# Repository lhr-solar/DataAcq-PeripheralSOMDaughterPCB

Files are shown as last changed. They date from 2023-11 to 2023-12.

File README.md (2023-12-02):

# Telemetry Peripheral SOM Daughterboard IMU
Author: Frank Li and Jim Fang

This board takes inputs from an IMU, airflow sensor, and three temp sensors and interfaces with the BPS Leader SOM.



## BOM

[**Mouser Cart**](https://www.mouser.com/ProjectManager/ProjectDetail.aspx?AccessID=6005ad65a9)

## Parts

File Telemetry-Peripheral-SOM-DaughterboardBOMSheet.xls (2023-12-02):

Mouser # | Mfr. # | Manufacturer | Description | Order Qty. | Price (USD) | Ext.: (USD)
 |  |  | 3.3V TestPoint (3.3V_TP1) | 1
 |  |  | 0.1u Capacitors (C1-C5, C8, C10, C12) | 8
 |  |  | 1u Capacitor (C6) | 1
 |  |  | 10n Capacitor (C7, C9, C11) | 3
875-HZ0805B222R-10 | HZ0805B222R-10 | Laird Performance Materials | 2.2K Ferrite Beads (FB1-FB3) | 3 | $0.15 | $0.45
 |  |  | GND TestPoint (GND_TP1) | 1
972-FS3000-1015 | FS3000-1015 | Renesas Electronics | Airflow Sensor (IC1) | 1 | $19.80 | $19.80
538-53307-2071 | 53307-2071 | Molex | Leader SOM Connector | 1 | $2.48 | $2.48
538-43650-0315 | 43650-0315 | Molex | Temperature Sensor Connectors (J2-J4) | 3 | $1.21 | $3.63
 |  |  | Mounting Holes (MH1, MH2) | 2
71-CRCW0805-50 | CRCW080550R0FKTA | Vishay | 50 Resistor (R1) | 1 | $0.25 | $0.25
755-SDR10EZPJ302 | SDR10EZPJ302 | ROHM Semiconductor | 3K Resistor (R2-R4) | 3 | $0.20 | $0.60
 |  |  | TestPoints for certain parts (TP1-TP5) | 5
511-LSM6DSVTR | LSM6DSVTR | STMicroelectronics | Inertial Motion Unit (U1) | 1 | $7.33 | $7.33

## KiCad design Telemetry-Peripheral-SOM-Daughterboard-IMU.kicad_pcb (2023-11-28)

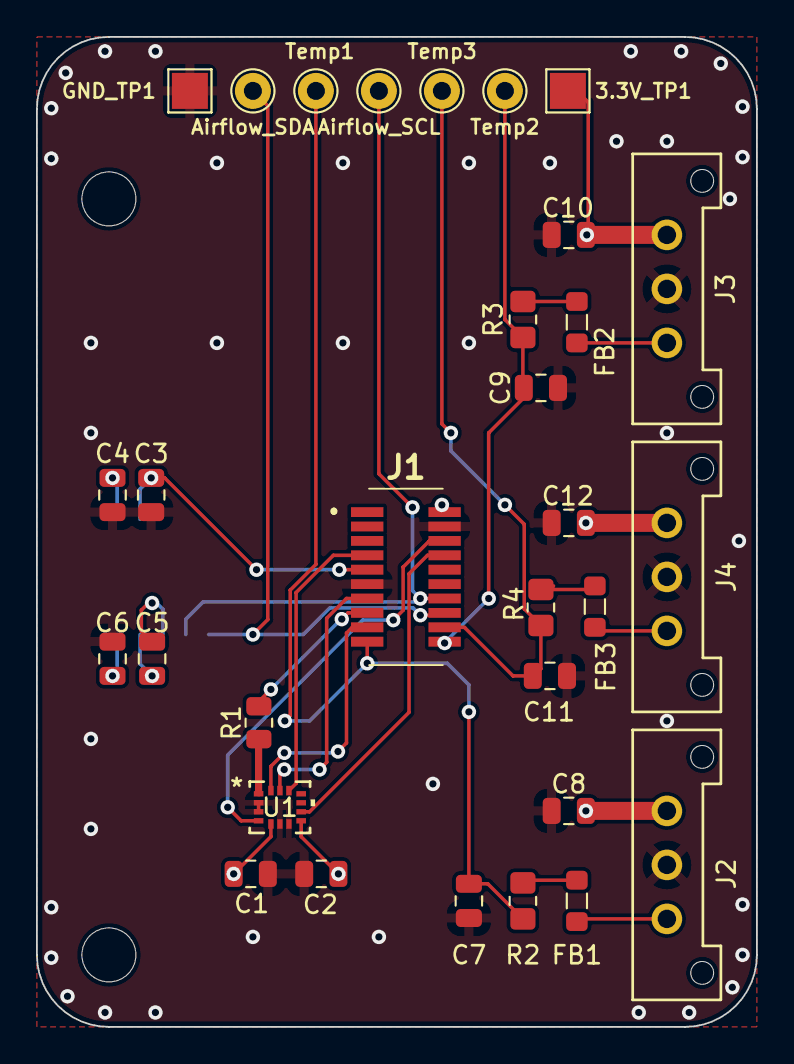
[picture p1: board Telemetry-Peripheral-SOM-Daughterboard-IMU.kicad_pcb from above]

Board: 2 copper layers, 40.0 x 55.0 mm, 34 parts (1 on the bottom side), 24 nets.

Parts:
3.3V_TP1: TestPoint; TestPoint_Pad_2.0x2.0mm
Airflow_SCL: TestPoint; TestPoint_THTPad_D2.0mm_Drill1.0mm
Airflow_SDA: TestPoint; TestPoint_THTPad_D2.0mm_Drill1.0mm
C1, C2, C3, C4, C5, C8, C10, C12: 0.1u; C_0805_2012Metric
C6: 1u; C_0805_2012Metric
C7, C9, C11: 10n; C_0805_2012Metric
FB1, FB2, FB3: 2.2k; L_0805_2012Metric_Pad1.05x1.20mm_HandSolder
GND_TP1: TestPoint; TestPoint_Pad_2.0x2.0mm
IC1: FS3000-1015; FS30001015
J1: Conn_02x10_Odd_Even; Molex_53307-2071
J2, J3, J4: Conn_01x03_Pin; Molex_MicroFit3.0_1x3xP3.00mm_PolarizingPeg_Vertical
MH1, MH2: M.3; MountingHole_3mm
R1: 50; R_0805_2012Metric
R2, R3, R4: 3k; R_0805_2012Metric_Pad1.20x1.40mm_HandSolder
Temp1, Temp2, Temp3: TestPoint; TestPoint_THTPad_D2.0mm_Drill1.0mm
U1: LSM6DSV; LGA14-L_2P59X3P1X0P5_STM

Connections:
+3.3V: 3.3V_TP1.1, C1.1, C2.1, C3.1, C8.1, C10.1, C12.1, IC1.2 (VIN), J1.2, J1.9, J2.1, J3.1, J4.1, U1.5 (VDD_IO), U1.8 (VDD)
/I2C1_SCL: Airflow_SCL.1, IC1.7 (SCL), J1.14
/I2C1_SDA: Airflow_SDA.1, IC1.6 (SDA), J1.16
/I2C2_SCL: J1.8, U1.9 (INT2)
/I2C2_SDA: J1.6, U1.4 (INT1)
/PA1: C9.1, J1.20, R3.1, Temp2.1
/PA2: C11.1, J1.18, R4.1, Temp3.1
/SPI1_MISO: J1.15, R1.1
/SPI1_MOSI: J1.17, U1.14 (SDA)
/SPI1_NSS: C7.1, J1.19, R2.1, Temp1.1
/SPI1_SCK: J1.13, U1.13 (SCL)
/SPI2_NSS: J1.7, U1.12 (CS)
GND: C1.2, C2.2, C3.2, C4.2, C6.2, C7.2, C8.2, C9.2, C10.2, C11.2, C12.2, GND_TP1.1, IC1.3 (GND), J1.4, J1.11, J2.2, J3.2, J4.2, U1.2 (SDX), U1.3 (SCX), U1.6 (GND), U1.7 (GND)
unnamed: FB1.1, R2.2
unnamed: FB2.1, R3.2
unnamed: FB3.1, R4.2
unnamed: C5.1, IC1.8 (TP1)
unnamed: C5.2, IC1.9 (TP2)
unnamed: C6.1, IC1.10 (VCM)
unnamed: C4.1, IC1.1 (VREG)
unnamed: FB1.2, J2.3
unnamed: FB2.2, J3.3
unnamed: FB3.2, J4.3
unnamed: R1.2, U1.1 (SDO/SA0)

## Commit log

2023-08-28 very basic daughterboard
    [Peripheral-SOM-Daughterboard.kicad_pcb, Telemetry-Peripheral-SOM-Daughterboard-IMU.kicad_pcb, Telemetry-Peripheral-SOM-Daughterboard-IMU.kicad_sch]
2023-09-29 created file for airflow sensor
    [Telemetry-Peripheral-SOM-Daughterboard-IMU.kicad_sch, airflowSensor.kicad_sch]
2023-09-29 created temperature sensor symbol and schematic
    [Telemetry-Peripheral-SOM-Daughterboard-IMU.kicad_sch, temperatureSensor.kicad_sch]
2023-09-30 Changes to airflow sch
    [airflowSensor.kicad_sch]
2023-09-30 updated temperature sensor
    [Telemetry-Peripheral-SOM-Daughterboard-IMU.kicad_sch, temperatureSensor.kicad_sch]
2023-09-30 temperatureSensor fix
    [Telemetry-Peripheral-SOM-Daughterboard-IMU.kicad_sch, airflowSensor.kicad_sch, temperatureSensor.kicad_sch]
2023-09-30 fixes to airflow sch
    [airflowSensor.kicad_sch]
2023-09-30 connected airflow and temperature sensors to connector J1
    [Telemetry-Peripheral-SOM-Daughterboard-IMU.kicad_sch, temperatureSensor.kicad_sch]
2023-09-30 fixed errors
    [Telemetry-Peripheral-SOM-Daughterboard-IMU.kicad_sch, airflowSensor.kicad_sch]
2023-09-30 temp sensor library fix
    [Telemetry-Peripheral-SOM-Daughterboard-IMU.kicad_pcb, temperatureSensor.kicad_sch]
2023-09-30 fixed symbol
    [temperatureSensor.kicad_sch]
2023-09-30 made imu sensor into a hierarchical sheet
    [Telemetry-Peripheral-SOM-Daughterboard-IMU.kicad_sch, imuSensor.kicad_sch]
2023-09-30 assigned footprints for all capacitors
    [Telemetry-Peripheral-SOM-Daughterboard-IMU.kicad_pcb, airflowSensor.kicad_sch, temperatureSensor.kicad_sch]
2023-10-06 fixed spi1_nss conflict, switched imu to spi2
    [Telemetry-Peripheral-SOM-Daughterboard-IMU.kicad_sch, imuSensor.kicad_sch, temperatureSensor.kicad_sch]
2023-10-07 first draft
    [Telemetry-Peripheral-SOM-Daughterboard-IMU.kicad_pcb, Telemetry-Peripheral-SOM-Daughterboard-IMU.kicad_sch, airflowSensor.kicad_sch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]
2023-10-07 added test points in schematic
    [Telemetry-Peripheral-SOM-Daughterboard-IMU.kicad_sch]
2023-10-14 PCB layout v1
    [Telemetry-Peripheral-SOM-Daughterboard-IMU.kicad_pcb]
2023-10-21 Integrated changes made by BPS
    [Telemetry-Peripheral-SOM-Daughterboard-IMU.kicad_pcb, Telemetry-Peripheral-SOM-Daughterboard-IMU.kicad_sch, temperatureSensor.kicad_sch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]
2023-10-21 added protective circuitry for temp sensors, made name changes for IMU
    [Telemetry-Peripheral-SOM-Daughterboard-IMU.kicad_sch, airflowSensor.kicad_sch, imuSensor.kicad_sch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]
2023-10-21 deleted uneeded temp sensor files
    [temperatureSensor2.kicad_sch, temperatureSensor3.kicad_sch]
2023-10-28 Attempting to merge
    [Telemetry-Peripheral-SOM-Daughterboard-IMU.kicad_pcb]
2023-10-28 added datasheet to schematic notes
2023-10-28 datasheet notes
    [temperatureSensor.kicad_sch]
2023-10-28 Name changes
    [Telemetry-Peripheral-SOM-Daughterboard-IMU.kicad_sch, imuSensor.kicad_sch]
2023-11-04 PCB changes
    [Telemetry-Peripheral-SOM-Daughterboard-IMU.kicad_pcb]
2023-11-04 Addressing PCB comments
    [Telemetry-Peripheral-SOM-Daughterboard-IMU.kicad_pcb]
2023-11-04 Temp sensor layout changes
    [Telemetry-Peripheral-SOM-Daughterboard-IMU.kicad_pcb]
2023-11-04 extended board for test points and connector
    [Telemetry-Peripheral-SOM-Daughterboard-IMU.kicad_pcb]
2023-11-04 shifted protective circuitry to be closer to connectors
    [Telemetry-Peripheral-SOM-Daughterboard-IMU.kicad_pcb]
2023-11-04 Aligning components
    [Telemetry-Peripheral-SOM-Daughterboard-IMU.kicad_pcb]
2023-11-04 Finalizing board layout changes
    [Telemetry-Peripheral-SOM-Daughterboard-IMU.kicad_pcb]
2023-11-04 added corner stitching and bom folder
    [PeripheralSOM-daughter-BOMSheet.xlsx]
2023-11-12 Changes to routing and silkscreen, addressed schematic error
    [Telemetry-Peripheral-SOM-Daughterboard-IMU.kicad_pcb, imuSensor.kicad_sch, temperatureSensor.kicad_sch]
2023-11-13 Removed unconnected trace ends
    [Telemetry-Peripheral-SOM-Daughterboard-IMU.kicad_pcb]
2023-11-13 Added gerbers
    [Telemetry-Peripheral-SOM-Daughterboard-IMU-B_Cu.gbl, Telemetry-Peripheral-SOM-Daughterboard-IMU-B_Mask.gbs, Telemetry-Peripheral-SOM-Daughterboard-IMU-B_Paste.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]
2023-11-14 added a BOM sheet
    [Telemetry-Peripheral-SOM-DaughterboardBOMSheet.xls]
2023-11-14 changes to BOM sheet
    [Telemetry-Peripheral-SOM-DaughterboardBOMSheet.xls]
2023-11-18 changes to I2C
    [Telemetry-Peripheral-SOM-Daughterboard-IMU.kicad_pcb, Telemetry-Peripheral-SOM-Daughterboard-IMU.kicad_sch]
2023-11-18 moved testPoints to top of board
    [Telemetry-Peripheral-SOM-Daughterboard-IMU.kicad_pcb]
2023-11-18 changes to silkscreen naming
    [Telemetry-Peripheral-SOM-Daughterboard-IMU.kicad_pcb]
2023-11-18 spaced out filtering components
    [Telemetry-Peripheral-SOM-Daughterboard-IMU.kicad_pcb]
2023-11-21 updated resistor datasheet
    [temperatureSensor.kicad_sch]
2023-11-21 zipped gerbers
    [Telemetry-Peripheral-SOM-Daughterboard-IMU-B_Cu.gbl, Telemetry-Peripheral-SOM-Daughterboard-IMU-B_Mask.gbs, Telemetry-Peripheral-SOM-Daughterboard-IMU-B_Paste.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]
2023-11-28 updated constraints and passed DRC
    [Telemetry-Peripheral-SOM-Daughterboard-IMU.kicad_pcb]
2023-11-28 updated gerbers
    [Telemetry-Peripheral-SOM-Daughterboard-IMU-B_Cu.gbl, Telemetry-Peripheral-SOM-Daughterboard-IMU-B_Mask.gbs, Telemetry-Peripheral-SOM-Daughterboard-IMU-B_Paste.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]
2023-12-02 changes to 3K resistor on excel BOM
    [Telemetry-Peripheral-SOM-DaughterboardBOMSheet.xls]
